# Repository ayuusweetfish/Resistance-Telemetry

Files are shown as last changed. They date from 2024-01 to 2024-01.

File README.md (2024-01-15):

# Resistance Telemetry

*🚧 Feature complete. Docs to be polished.*

A compact sensor for a variable resistance that transmits data through BLE. A client program provides an interface for plotting and inspecting values on a desktop computer.

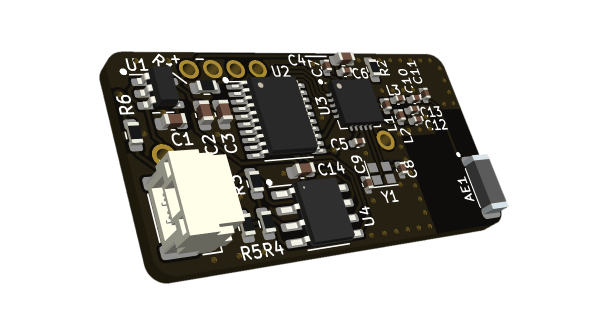
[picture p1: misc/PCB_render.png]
Rendering of the circuit board


The device is physically compact (3.3 cm × 1.7 cm, around the size of the battery cell plus the antenna). It is powered by a LIR2016 cell and requires no setup on the computer side. Resolution is 24-bit, but no extensive calibration has currently been carried out. Designed for laboratory use, e.g. for e-skin gloves user studies.

## Directory structure

- **hardware/**: Circuit board design files.
- **firmware/**: Firmware (PlatformIO / C).
- **client/**: The client in C++. A Windows build is automated through [GitHub Actions](https://github.com/ayuusweetfish/Resistance-Telemetry/actions).
- **misc/**: Miscellaneous files and backups.
  - **STM32F1_test1/**: Test BLE transmission on a [blue pill](https://stm32-base.org/boards/STM32F103C8T6-Blue-Pill.html) board.
  - **compress_24b.c**: Data compression through least-squares quadratic fitting. Not employed in the final version due to nonnecessity for further enhancement.

## Permit

All content in this repository is released under [CC BY-NC-SA 4.0](https://creativecommons.org/licenses/by-nc-sa/4.0/). Additionally, software source code is dual-licensed by [Hippocratic License 2.1](https://spdx.org/licenses/Hippocratic-2.1.html).

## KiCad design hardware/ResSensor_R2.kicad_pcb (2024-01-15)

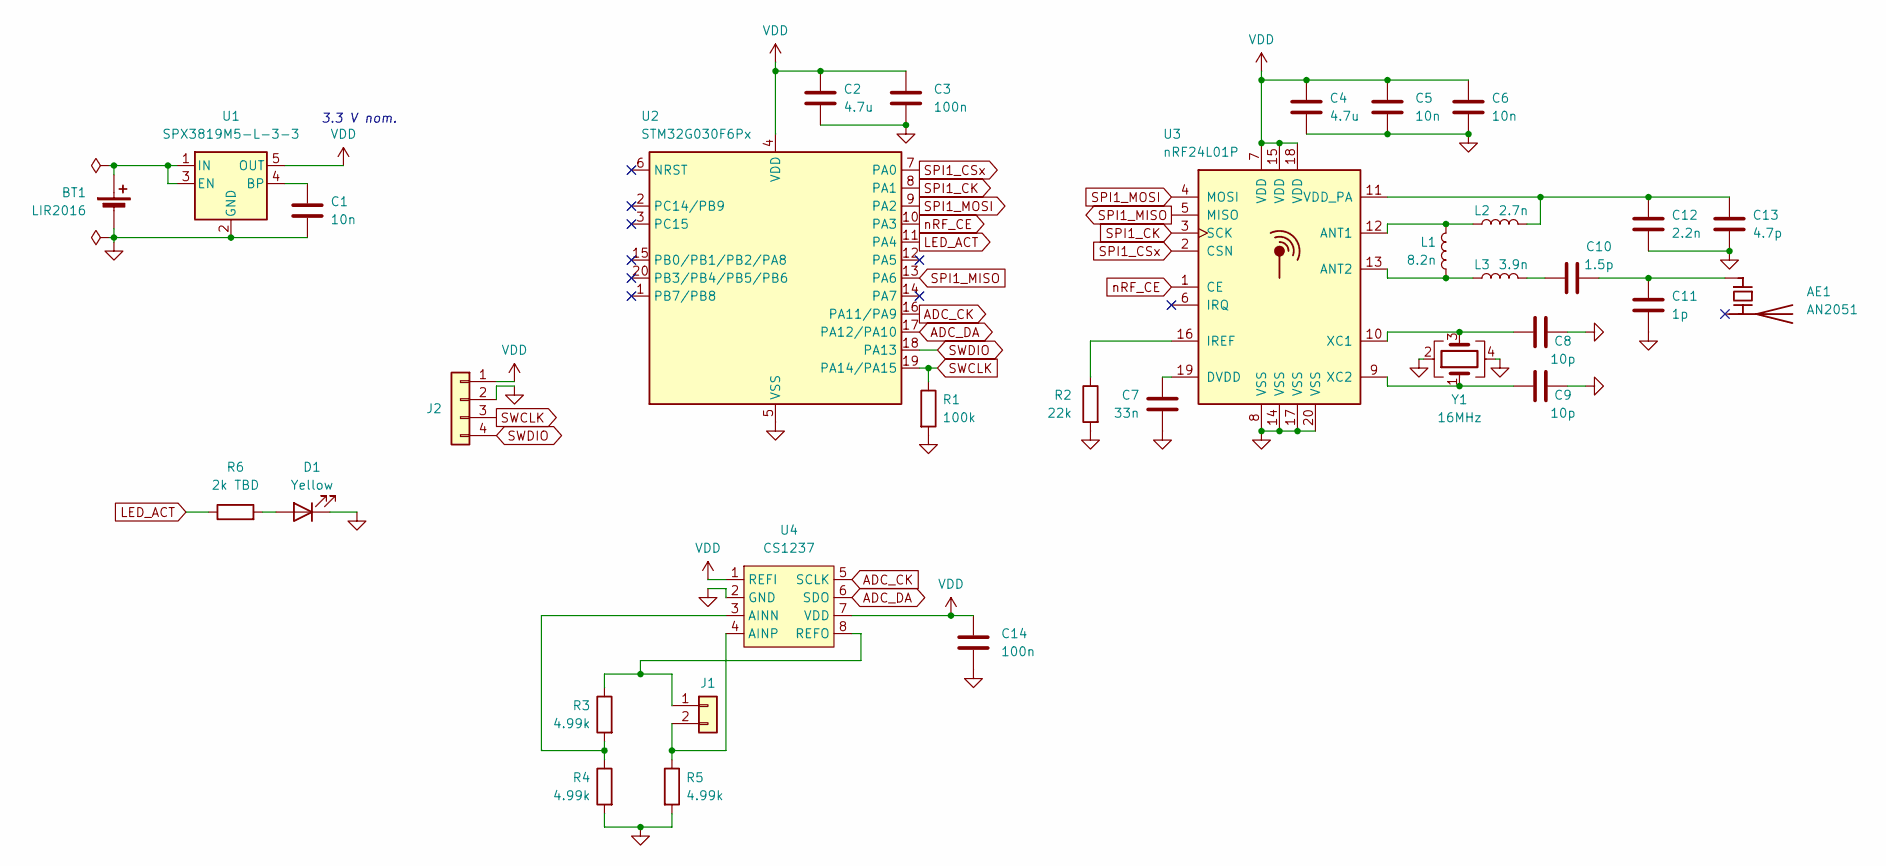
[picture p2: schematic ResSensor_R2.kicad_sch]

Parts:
AE1: AN2051; ANTC5020X127N
BT1: LIR2016; BatteryHolder_2032_THT_P20
C1: 10n; C_0603_1608Metric
C2, C4: 4.7u; C_0603_1608Metric
C3, C14: 100n; C_0603_1608Metric
C5, C6: 10n; C_0402_1005Metric
C7: 33n; C_0402_1005Metric
C8, C9: 10p; C_0402_1005Metric
C10: 1.5p; C_0402_1005Metric
C11: 1p; C_0402_1005Metric
C12: 2.2n; C_0402_1005Metric
C13: 4.7p; C_0402_1005Metric
D1: Yellow; LED_0603_1608Metric
J1: Conn_01x02; JST_GH_SM02B-GHS-TB_1x02-1MP_P1.25mm_Horizontal
J2: Conn_01x04; TestPoints_1x04_P2.0
L1: 8.2n; C_0402_1005Metric
L2: 2.7n; C_0402_1005Metric
L3: 3.9n; C_0402_1005Metric
R1: 100k; R_0603_1608Metric
R2: 22k; R_0603_1608Metric
R3, R4, R5: 4.99k; R_0603_1608Metric
R6: 2k TBD; R_0603_1608Metric
U1: SPX3819M5-L-3-3; SOT-23-5
U2: STM32G030F6Px; TSSOP-20_4.4x6.5mm_P0.65mm
U3: nRF24L01P; QFN-20-P0.5
U4: CS1237; SOP-8_3.76x4.96mm_P1.27mm
Y1: 16MHz; Crystal_SMD_2016-4Pin_2.0x1.6mm

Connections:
ADC_CK: U2.16 (PA11/PA9), U4.5 (SCLK)
ADC_DA: U2.17 (PA12/PA10), U4.6 (SDO)
GND: BT1.2 (-), C1.2, C2.2, C3.2, C4.2, C5.2, C6.2, C7.2, C8.2, C9.2, C11.2, C12.2, C13.2, C14.2, D1.1 (K), J2.2, R1.2, R2.2, R4.2, R5.2, U1.2 (GND), U2.5 (VSS), U3.8 (VSS), U3.14 (VSS), U3.17 (VSS), U3.20 (VSS), U4.2 (GND), Y1.2, Y1.4
LED_ACT: R6.1, U2.11 (PA4)
unnamed: AE1.1 (FEED), C10.2, C11.1
unnamed: BT1.1 (+), U1.1 (IN), U1.3 (EN)
unnamed: C10.1, L3.2
unnamed: D1.2 (A), R6.2
unnamed: J1.1, R3.1, U4.8 (REFO)
unnamed: J1.2, R5.1, U4.4 (AINP)
unnamed: C1.1, U1.4 (BP)
unnamed: L1.1, L2.1, U3.12 (ANT1)
unnamed: L1.2, L3.1, U3.13 (ANT2)
unnamed: C7.1, U3.19 (DVDD)
unnamed: R2.1, U3.16 (IREF)
unnamed: C12.1, C13.1, L2.2, U3.11 (VDD_PA)
unnamed: C8.1, U3.10 (XC1), Y1.3
unnamed: C9.1, U3.9 (XC2), Y1.1
unnamed: R3.2, R4.1, U4.3 (AINN)
SPI1_CK: U2.8 (PA1), U3.3 (SCK)
SPI1_CSx: U2.7 (PA0), U3.2 (CSN)
SPI1_MISO: U2.13 (PA6), U3.5 (MISO)
SPI1_MOSI: U2.9 (PA2), U3.4 (MOSI)
SWCLK: J2.3, R1.1, U2.19 (PA14/PA15)
SWDIO: J2.4, U2.18 (PA13)
VDD: C2.1, C3.1, C4.1, C5.1, C6.1, C14.1, J2.1, U1.5 (OUT), U2.4 (VDD), U3.7 (VDD), U3.15 (VDD), U3.18 (VDD), U4.1 (REFI), U4.7 (VDD)
nRF_CE: U2.10 (PA3), U3.1 (CE)

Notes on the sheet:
3.3 V nom.

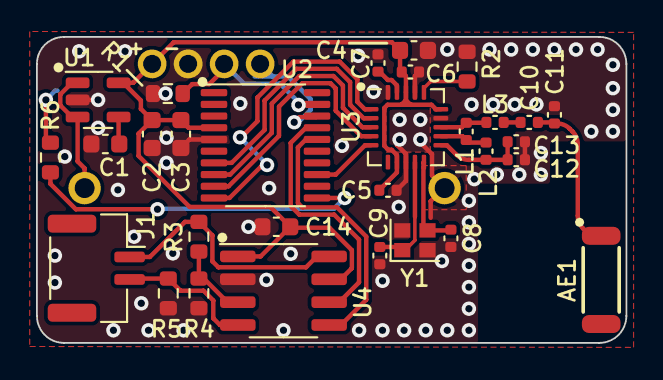
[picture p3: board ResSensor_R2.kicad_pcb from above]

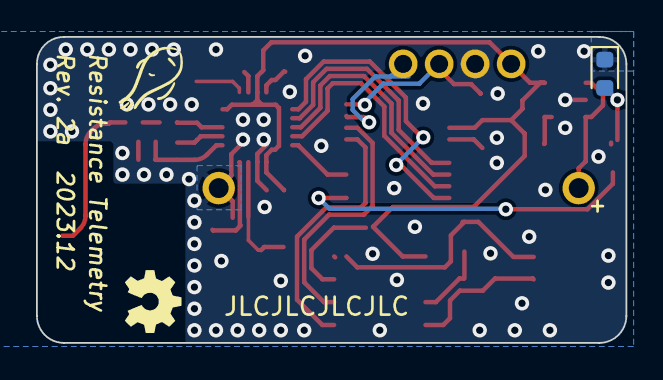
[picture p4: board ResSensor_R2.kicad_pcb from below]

Board: 2 copper layers, 32.8 x 17.0 mm, 33 parts (2 on the bottom side), 27 nets.

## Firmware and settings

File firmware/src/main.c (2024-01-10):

#include <stm32g0xx_hal.h>
#include <stdarg.h>
#include <stdbool.h>
#include <stdint.h>
#include <stdio.h>

#define LED_PORT    GPIOA
#define LED_PIN_ACT GPIO_PIN_4

#define RELEASE
#ifndef RELEASE
static uint8_t swv_buf[256];
static size_t swv_buf_ptr = 0;
__attribute__ ((noinline, used))
void swv_trap_line()
{
  *(volatile char *)swv_buf;
}
static inline void swv_putchar(uint8_t c)
{
  // ITM_SendChar(c);
  if (c == '\n') {
    swv_buf[swv_buf_ptr >= sizeof swv_buf ?
      (sizeof swv_buf - 1) : swv_buf_ptr] = '\0';
    swv_trap_line();
    swv_buf_ptr = 0;
  } else if (++swv_buf_ptr <= sizeof swv_buf) {
    swv_buf[swv_buf_ptr - 1] = c;
  }
}
static void swv_printf(const char *restrict fmt, ...)
{
  char s[256];
  va_list args;
  va_start(args, fmt);
  int r = vsnprintf(s, sizeof s, fmt, args);
  for (int i = 0; i < r && i < sizeof s - 1; i++) swv_putchar(s[i]);
  if (r >= sizeof s) {
    for (int i = 0; i < 3; i++) swv_putchar('.');
    swv_putchar('\n');
  }
}
#else
#define swv_printf(...)
#endif

#define PIN_ADC_CK  GPIO_PIN_11
#define PIN_ADC_DA  GPIO_PIN_12
void adc_configure();

SPI_HandleTypeDef spi1 = { 0 };
#define PIN_nRF_CS  GPIO_PIN_0
#define PIN_nRF_CE  GPIO_PIN_3

TIM_HandleTypeDef tim14;

// Disabled; see notes in main()
// ADC_HandleTypeDef adc1 = { 0 };

static inline void sleep_delay(uint32_t ticks) {
  uint32_t start_tick = HAL_GetTick();
  while (HAL_GetTick() - start_tick < ticks + 1)
    HAL_PWR_EnterSLEEPMode(PWR_MAINREGULATOR_ON, PWR_SLEEPENTRY_WFI);
}
#define HAL_Delay sleep_delay

static inline void nRF_send_len(const uint8_t *cmd, uint32_t size)
{
  HAL_GPIO_WritePin(GPIOA, PIN_nRF_CS, GPIO_PIN_RESET);
  HAL_SPI_Transmit(&spi1, (uint8_t *)cmd, size, 1000);
  HAL_GPIO_WritePin(GPIOA, PIN_nRF_CS, GPIO_PIN_SET);
}
#define nRF_send(...) do { \
  uint8_t buf[] = {__VA_ARGS__}; \
  nRF_send_len(buf, sizeof buf); \
} while (0)

static inline uint8_t bit_rev(uint8_t x)
{
  x = (x & 0b00001111) << 4 | (x & 0b11110000) >> 4;
  x = (x & 0b00110011) << 2 | (x & 0b11001100) >> 2;
  x = (x & 0b01010101) << 1 | (x & 0b10101010) >> 1;
  return x;
}

static inline void ble_encode_packet(uint8_t *packet, uint8_t len, uint8_t ch)
{
  // CRC
  uint8_t crc[3] = {0x55, 0x55, 0x55};
  for (uint8_t i = 0; i < len; i++) {
    uint8_t d = packet[i];
    for (uint8_t v = 0; v < 8; v++, d >>= 1) {
      uint8_t t = 0;
      if (crc[0] & 0x80) { t = 1;       } crc[0] <<= 1;
      if (crc[1] & 0x80) { crc[0] |= 1; } crc[1] <<= 1;
      if (crc[2] & 0x80) { crc[1] |= 1; } crc[2] <<= 1;
      if (t != (d & 1)) {
        crc[2] ^= 0x5B;
        crc[1] ^= 0x06;
      }
    }
  }
  packet[len + 0] = bit_rev(crc[0]);
  packet[len + 1] = bit_rev(crc[1]);
  packet[len + 2] = bit_rev(crc[2]);

  // Whiten
  uint8_t whiten_coeff = bit_rev(ch) | 2;
  for (uint8_t i = 0; i < len + 3; i++) {
    for (uint8_t m = 1; m != 0; m <<= 1) {
      if (whiten_coeff & 0x80) {
        whiten_coeff ^= 0x11;
        packet[i] ^= m;
      }
      whiten_coeff <<= 1;
    }
  }

  // Reverse all bits
  for (uint8_t i = 0; i < len + 3; i++)
    packet[i] = bit_rev(packet[i]);
}

static inline void write_bits(uint8_t *buffer, size_t start, size_t length, uint32_t value)
{
  for (int i = 0; i < length; i++) {
    int index = (start + i) / 8;
    int bitpos = (start + i) % 8;
    if (value & (1 << i))
      buffer[index] |= (1 << bitpos);
    else
      buffer[index] &= ~(1 << bitpos);
  }
}

static volatile uint32_t adc_value = 0;
static volatile uint8_t adc_updated = 0;

int main()
{
  HAL_Init();

  // ======== GPIO ========
  __HAL_RCC_GPIOA_CLK_ENABLE();
  GPIO_InitTypeDef gpio_init;

  gpio_init.Pin = LED_PIN_ACT;
  gpio_init.Mode = GPIO_MODE_OUTPUT_PP;
  gpio_init.Pull = GPIO_PULLUP;
  gpio_init.Speed = GPIO_SPEED_FREQ_HIGH;
  HAL_GPIO_Init(LED_PORT, &gpio_init);
  HAL_GPIO_WritePin(LED_PORT, LED_PIN_ACT, GPIO_PIN_RESET);

  // SWD (PA13, PA14)
  gpio_init.Pin = GPIO_PIN_13 | GPIO_PIN_14;
  gpio_init.Mode = GPIO_MODE_AF_PP; // Pass over control to AF peripheral
  gpio_init.Alternate = GPIO_AF0_SWJ;
  gpio_init.Pull = GPIO_PULLUP;
  gpio_init.Speed = GPIO_SPEED_FREQ_HIGH;
  HAL_GPIO_Init(GPIOA, &gpio_init);

  // Clocks
  RCC_OscInitTypeDef osc_init = { 0 };
  osc_init.OscillatorType = RCC_OSCILLATORTYPE_HSI;
  osc_init.HSIState = RCC_HSI_ON;
  osc_init.HSIDiv = RCC_HSI_DIV8;
  osc_init.PLL.PLLState = RCC_PLL_OFF;
  HAL_RCC_OscConfig(&osc_init);

  RCC_ClkInitTypeDef clk_init = { 0 };
  clk_init.ClockType =
    RCC_CLOCKTYPE_SYSCLK |
    RCC_CLOCKTYPE_HCLK |
    RCC_CLOCKTYPE_PCLK1;
  clk_init.SYSCLKSource = RCC_SYSCLKSOURCE_HSI; // SYSCLK = HCLK = 2 MHz
  clk_init.AHBCLKDivider = RCC_SYSCLK_DIV1;
  clk_init.APB1CLKDivider = RCC_HCLK_DIV1;
  HAL_RCC_ClockConfig(&clk_init, FLASH_LATENCY_2);

  HAL_NVIC_SetPriority(SysTick_IRQn, 0, 0);

  HAL_GPIO_WritePin(GPIOA, PIN_ADC_CK, GPIO_PIN_SET);

  // ======== SPIx ADC ========
  HAL_Delay(1);
  // ADC_CK
  gpio_init.Pin = PIN_ADC_CK;
  gpio_init.Mode = GPIO_MODE_OUTPUT_PP;
  gpio_init.Pull = GPIO_NOPULL;
  gpio_init.Speed = GPIO_SPEED_FREQ_HIGH;
  HAL_GPIO_Init(GPIOA, &gpio_init);
  // ADC_DA
  gpio_init.Pin = PIN_ADC_DA;
  gpio_init.Mode = GPIO_MODE_INPUT;
  gpio_init.Pull = GPIO_NOPULL;
  gpio_init.Speed = GPIO_SPEED_FREQ_HIGH;
  HAL_GPIO_Init(GPIOA, &gpio_init);

  HAL_GPIO_WritePin(GPIOA, PIN_ADC_CK, GPIO_PIN_RESET);
  HAL_Delay(1);
  // Wait for DRDY (not necessary — see below)
  // while (HAL_GPIO_ReadPin(GPIOA, PIN_ADC_DA) == GPIO_PIN_SET) { }
  // XXX: Are these unarticulated design aspects inside CS1237?
  //   Configuration cannot be processed when data conversion is in progress?
  //   DRDY is still present when data is invalid during the first 3/4 samples?
  // Anyway, blink the LED while we wait
  HAL_GPIO_WritePin(LED_PORT, LED_PIN_ACT, GPIO_PIN_SET);
  HAL_Delay(160);
  HAL_GPIO_WritePin(LED_PORT, LED_PIN_ACT, GPIO_PIN_RESET);
  HAL_Delay(160);
  adc_configure();  // Read data (discarded) and configure
  HAL_GPIO_WritePin(LED_PORT, LED_PIN_ACT, GPIO_PIN_SET);
  HAL_Delay(320);   // Skip 3 samples, otherwise the first few read-outs are zero
  HAL_GPIO_WritePin(LED_PORT, LED_PIN_ACT, GPIO_PIN_RESET);

  // PA12 - EXTI line 12
  HAL_NVIC_SetPriority(EXTI4_15_IRQn, 2, 0);
  HAL_NVIC_EnableIRQ(EXTI4_15_IRQn);

  // Pull down clock / chip select signal and wait for DRDY
  HAL_GPIO_WritePin(GPIOA, PIN_ADC_CK, GPIO_PIN_RESET);

  // ======== SPI ========
  // GPIO ports
  // SPI1_SCK (PA1), SPI1_MOSI (PA2), SPI1_MISO (PA6)
  gpio_init.Pin = GPIO_PIN_1 | GPIO_PIN_2 | GPIO_PIN_6;
  gpio_init.Mode = GPIO_MODE_AF_PP;
  gpio_init.Alternate = GPIO_AF0_SPI1;
  gpio_init.Pull = GPIO_NOPULL;
  gpio_init.Speed = GPIO_SPEED_FREQ_HIGH;
  HAL_GPIO_Init(GPIOA, &gpio_init);
  // nRF24L01+ CSN (PA0)
  gpio_init.Mode = GPIO_MODE_OUTPUT_PP;
  gpio_init.Pin = PIN_nRF_CS | PIN_nRF_CE;
  HAL_GPIO_Init(GPIOA, &gpio_init);
  HAL_GPIO_WritePin(GPIOA, PIN_nRF_CS, GPIO_PIN_SET);
  HAL_GPIO_WritePin(GPIOA, PIN_nRF_CE, GPIO_PIN_RESET);

  __HAL_RCC_SPI1_CLK_ENABLE();
  spi1.Instance = SPI1;
  spi1.Init.Mode = SPI_MODE_MASTER;
  spi1.Init.Direction = SPI_DIRECTION_2LINES;
  spi1.Init.CLKPolarity = SPI_POLARITY_LOW; // CPOL = 0
  spi1.Init.CLKPhase = SPI_PHASE_1EDGE;     // CPHA = 0
  spi1.Init.NSS = SPI_NSS_SOFT;
  spi1.Init.FirstBit = SPI_FIRSTBIT_MSB;
  spi1.Init.TIMode = SPI_TIMODE_DISABLE;
  spi1.Init.CRCCalculation = SPI_CRCCALCULATION_DISABLE;
  spi1.Init.DataSize = SPI_DATASIZE_8BIT;
  spi1.Init.BaudRatePrescaler = SPI_BAUDRATEPRESCALER_2;
  HAL_SPI_Init(&spi1);
  __HAL_SPI_ENABLE(&spi1);

  // Set up nRF24L01+
  nRF_send(0x20, 0x72); // CONFIG: Disable IRQ and CRC, power up
  nRF_send(0x21, 0x00); // EN_AA: Disable auto ack.
  nRF_send(0x22, 0x00); // EN_RXADDR: Disable RX completely
  nRF_send(0x23, 0x02); // SETUP_AW: 4-byte address
  nRF_send(0x24, 0x00); // SETUP_RETR: Disable auto restransmission
  nRF_send(0x26, 0x06); // RF_SETUP: 1 Mbps, 0 dBm
  nRF_send(0x27, 0x70); // STATUS: Clear status flags
  // nRF_send(0x31, 32);   // RX_PW_P0: Pipe 0 payload length 32 bytes
  nRF_send(0x22, 0x01); // EN_RXADDR: Enable RX on pipe 0
  // nRF_send(0x2A, bit_rev(0x8E), bit_rev(0x89), bit_rev(0xBE), bit_rev(0xD6));
    // RX_ADDR_P0: Set pipe 0 receive address
  nRF_send(0x30, bit_rev(0x8E), bit_rev(0x89), bit_rev(0xBE), bit_rev(0xD6));
    // TX_ADDR: Set transmit address

  // Read register 0x06 (RF_SETUP)
  HAL_GPIO_WritePin(GPIOA, PIN_nRF_CS, GPIO_PIN_RESET);
  uint8_t spi_tx[2] = {0x06, 0x00};
  uint8_t spi_rx[2];
  HAL_SPI_TransmitReceive(&spi1, spi_tx, spi_rx, 2, 1000);
  HAL_GPIO_WritePin(GPIOA, PIN_nRF_CS, GPIO_PIN_SET);
  swv_printf("received data = %02x %02x\n", spi_rx[0], spi_rx[1]);
  if (spi_rx[0] != 0x0E || spi_rx[1] != 0x06) {
    // Error? Try a reset
    for (int i = 0; i < 11; i++) {
      HAL_GPIO_WritePin(LED_PORT, LED_PIN_ACT, i % 2);
      HAL_Delay(60);
    }
    HAL_Delay(500);
    NVIC_SystemReset();
  }

  // ======== Timer ========
  // APB1 = 2 MHz
  // period = 1 kHz = 2000 cycles
  // Act LED, TIM14
  gpio_init.Pin = LED_PIN_ACT;
  gpio_init.Mode = GPIO_MODE_AF_PP;
  gpio_init.Alternate = GPIO_AF4_TIM14;
  gpio_init.Pull = GPIO_NOPULL;
  gpio_init.Speed = GPIO_SPEED_FREQ_HIGH;
  HAL_GPIO_Init(LED_PORT, &gpio_init);
  __HAL_RCC_TIM14_CLK_ENABLE();
  tim14 = (TIM_HandleTypeDef){
    .Instance = TIM14,
    .Init = {
      .Prescaler = 1 - 1,
      .CounterMode = TIM_COUNTERMODE_UP,
      .Period = 2000 - 1,
      .ClockDivision = TIM_CLOCKDIVISION_DIV1,
      .RepetitionCounter = 0,
    },
  };
  HAL_TIM_PWM_Init(&tim14);
  TIM_OC_InitTypeDef tim14_ch1_oc_init = {
    .OCMode = TIM_OCMODE_PWM1,
    .Pulse = 0, // to be filled
    .OCPolarity = TIM_OCPOLARITY_HIGH,
  };
  HAL_TIM_PWM_ConfigChannel(&tim14, &tim14_ch1_oc_init, TIM_CHANNEL_1);
  HAL_TIM_PWM_Start(&tim14, TIM_CHANNEL_1);
/*
from math import *
N=256
print(', '.join('%d' % round(600*((1+sin(i/N*2*pi))/2)**2) for i in range(N)))
*/
  static const uint16_t LED_STEPS[] = {
150, 157, 165, 173, 181, 189, 197, 206, 214, 223, 232, 241, 250, 259, 268, 277, 287, 296, 306, 315, 325, 334, 344, 353, 363, 372, 382, 391, 401, 410, 419, 428, 437, 446, 455, 463, 472, 480, 488, 496, 503, 511, 518, 525, 531, 538, 544, 550, 555, 560, 565, 570, 574, 578, 582, 586, 589, 591, 594, 595, 597, 598, 599, 600, 600, 600, 599, 598, 597, 595, 594, 591, 589, 586, 582, 578, 574, 570, 565, 560, 555, 550, 544, 538, 531, 525, 518, 511, 503, 496, 488, 480, 472, 463, 455, 446, 437, 428, 419, 410, 401, 391, 382, 372, 363, 353, 344, 334, 325, 315, 306, 296, 287, 277, 268, 259, 250, 241, 232, 223, 214, 206, 197, 189, 181, 173, 165, 157, 150, 143, 136, 129, 122, 116, 109, 103, 97, 91, 86, 81, 76, 71, 66, 61, 57, 53, 49, 45, 42, 39, 35, 32, 30, 27, 25, 22, 20, 18, 16, 14, 13, 11, 10, 9, 8, 7, 6, 5, 4, 4, 3, 3, 2, 2, 1, 1, 1, 1, 1, 0, 0, 0, 0, 0, 0, 0, 0, 0, 0, 0, 0, 0, 0, 0, 0, 0, 0, 0, 0, 0, 0, 0, 0, 0, 0, 0, 1, 1, 1, 1, 1, 2, 2, 3, 3, 4, 4, 5, 6, 7, 8, 9, 10, 11, 13, 14, 16, 18, 20, 22, 25, 27, 30, 32, 35, 39, 42, 45, 49, 53, 57, 61, 66, 71, 76, 81, 86, 91, 97, 103, 109, 116, 122, 129, 136, 143
  };

  // ======== On-chip ADC ========
  // Disabled; HAL_ADC_GetValue() disturbs timing of CS1237?
/*
  __HAL_RCC_ADC_CLK_ENABLE();
  adc1.Instance = ADC1;
  adc1.Init.ClockPrescaler = ADC_CLOCK_ASYNC_DIV1;
  adc1.Init.Resolution = ADC_RESOLUTION_12B;
  adc1.Init.DataAlign = ADC_DATAALIGN_RIGHT;
  adc1.Init.ScanConvMode = ADC_SCAN_DISABLE;
  adc1.Init.EOCSelection = ADC_EOC_SINGLE_CONV;
  adc1.Init.LowPowerAutoWait = DISABLE;
  adc1.Init.LowPowerAutoPowerOff = ENABLE;
  adc1.Init.ContinuousConvMode = DISABLE;
  adc1.Init.NbrOfConversion = 1;
  adc1.Init.DiscontinuousConvMode = DISABLE;
  adc1.Init.ExternalTrigConv = ADC_SOFTWARE_START;
  adc1.Init.TriggerFrequencyMode = ADC_TRIGGER_FREQ_LOW;
  HAL_ADC_Init(&adc1);

  ADC_ChannelConfTypeDef adc_ch;
  adc_ch.Channel = ADC_CHANNEL_VREFINT;
  adc_ch.Rank = ADC_REGULAR_RANK_1;
  adc_ch.SamplingTime = ADC_SAMPLETIME_79CYCLES_5; // Stablize
  HAL_ADC_ConfigChannel(&adc1, &adc_ch);

  HAL_ADCEx_Calibration_Start(&adc1);

  HAL_ADC_Start(&adc1);
  HAL_ADC_PollForConversion(&adc1, 1000);
  uint32_t adc_value = HAL_ADC_GetValue(&adc1);
  HAL_ADC_Stop(&adc1);
  uint32_t vdd_mV = 3000 * *VREFINT_CAL_ADDR / adc_value;
  swv_printf("ADC ref = %lu\n", *VREFINT_CAL_ADDR);
  swv_printf("ADC value = %lu, VDD = %lu mV\n", adc_value, vdd_mV);
  if (vdd_mV < 3100) {
    // Blinks: wait + 2 short + (1 long per 100 mV drop)
    HAL_Delay(200);
    for (int i = 0; i < 2; i++) {
      TIM14->CCR1 = 4000; HAL_Delay(60);
      TIM14->CCR1 = 0; HAL_Delay(60);
    }
    int blinks = (3100 - vdd_mV) / 100 + 1;
    for (int i = 0; i < blinks; i++) {
      TIM14->CCR1 = 4000; HAL_Delay(120);
      TIM14->CCR1 = 0; HAL_Delay(120);
    }
  }
*/

  uint8_t nrf_ch[3] = { 2, 26, 80};
  uint8_t ble_ch[3] = {37, 38, 39};
  uint8_t cur_ch = 2;

  uint8_t led_phase = 0;
  uint16_t timestamp = 0;
  uint32_t collected_data[15] = { 0 };

  uint8_t cur_offset_counter = 0;
  uint8_t startup_counter = 0;  // Counts up to 15, then stops

  while (!adc_updated) { }  // Wait for the first sample

  uint32_t last_tick = HAL_GetTick();
  while (true) {
    cur_ch = (cur_ch + 1) % 3;
    if (adc_updated) {
      timestamp += 1;   // May overflow and wrap around
      if (startup_counter < 15) startup_counter++;
      for (int i = 14; i > 0; i--) collected_data[i] = collected_data[i - 1];
      collected_data[0] = adc_value;
      adc_updated = 0;
      cur_offset_counter = 0;
    } else {
      cur_offset_counter = (cur_offset_counter + 1) % 5;
    }

    // Payload format:
    // 10 bits timestamp
    // 22*5 bits data
    uint8_t cur_offset =
      (cur_offset_counter < 3 ? 0 : (cur_offset_counter - 2) * 5);
    if (startup_counter >= 5 && startup_counter < 15) {
      // Prevent out-of-bound data
      if (cur_offset + 5 > startup_counter)
        cur_offset = startup_counter - 5;
    }
    uint8_t tx_payload[15];
    uint16_t tx_timestamp = (timestamp - cur_offset) & ((1 << 10) - 1);
    write_bits(tx_payload, 0, 10, tx_timestamp);
    for (int i = 0; i < 5; i++)
      write_bits(tx_payload, 10 + i * 22, 22,
        collected_data[cur_offset + i] >> 2);

    uint8_t nRF_cmd_buf[33];
    uint8_t *buf = nRF_cmd_buf + 1;
    uint8_t p = 0;
    // PDU - Protocol Data Unit
    // AD - Advertising Data
    // For assigned numbers, see https://www.bluetooth.com/specifications/an/
    // PDU header
    buf[p++] = 0x42;  // Type: ADV_NONCONN_IND; TxAdd is random
    buf[p++] = 0;     // Payload length, to be filled
    // PDU payload
    buf[p++] = 0x48;  // Address (byte reversed)
    buf[p++] = 0xFE;
    buf[p++] = 0x21;
    buf[p++] = 0x61;
    buf[p++] = 0x75;
    buf[p++] = 0xCB;  // Highest bit should be set
  /*
    buf[p++] = 2;     // AD length
    buf[p++] = 0x01;  // Type: Flags
    buf[p++] = 0x05;
  */
    buf[p++] = 3;     // AD length
    buf[p++] = 0x08;  // Type: Shortened Local Name
    buf[p++] = 'R';
    buf[p++] = 'T';
    buf[p++] = 16;    // AD length
    buf[p++] = 0xFF;  // Type: Manufacturer Specific Data
    for (int i = 0; i < 15; i++) buf[p++] = tx_payload[i];
    buf[1] = p - 2;   // Payload length

    // Encode packet
    ble_encode_packet(buf, p, ble_ch[cur_ch]);

    nRF_send(0x25, nrf_ch[cur_ch]); // RF_CH: Set channel
    nRF_send(0x27, 0x70); // STATUS: Clear status flags
    nRF_send(0xE1); // FLUSH_TX
    nRF_send(0xE2); // FLUSH_RX
    nRF_cmd_buf[0] = 0xA0;  // W_TX_PAYLOAD
    nRF_send_len(nRF_cmd_buf, p + 4);
    HAL_GPIO_WritePin(GPIOA, PIN_nRF_CE, GPIO_PIN_SET);
    HAL_Delay(2);
    HAL_GPIO_WritePin(GPIOA, PIN_nRF_CE, GPIO_PIN_RESET);

    TIM14->CCR1 = LED_STEPS[++led_phase];
    swv_printf("ADC value = %06x\n", collected_data[0]);

    // Accurate delay
    uint32_t cur_tick = HAL_GetTick();
    if (cur_tick - last_tick >= 18) {
      last_tick = cur_tick;
    } else {
      while (HAL_GetTick() - last_tick < 18)
        HAL_PWR_EnterSLEEPMode(PWR_MAINREGULATOR_ON, PWR_SLEEPENTRY_WFI);
      last_tick += 18;
    }
  }
}

void SysTick_Handler()
{
  HAL_IncTick();
  HAL_SYSTICK_IRQHandler();
}

static inline void adc_ser_delay()
{
  // >= 0.5 us
  // SYSCLK = 2 MHz, 0.5 us is 1 cycle
  for (volatile int i = 0; i < 2; i++) asm volatile ("nop");
}

inline void adc_configure()
{
  GPIO_InitTypeDef gpio_init;
  gpio_init.Pin = PIN_ADC_DA;
  gpio_init.Pull = GPIO_NOPULL;
  gpio_init.Speed = GPIO_SPEED_FREQ_HIGH;

  HAL_GPIO_WritePin(GPIOA, PIN_ADC_CK, GPIO_PIN_RESET);
  adc_ser_delay();
  for (int i = 0; i < 29; i++) {
    HAL_GPIO_WritePin(GPIOA, PIN_ADC_CK, GPIO_PIN_SET);
    adc_ser_delay();
    HAL_GPIO_WritePin(GPIOA, PIN_ADC_CK, GPIO_PIN_RESET);
    adc_ser_delay();
  }

  gpio_init.Mode = GPIO_MODE_OUTPUT_PP;
  HAL_GPIO_Init(GPIOA, &gpio_init);
  // SPEED_SEL = 0b00: 10 Hz
  // PGA_SEL = 00: PGA gain = 1
  // ADC value normalized to [-0.5, +0.5)
  // Calculated R = R5 (see hardware design) * (1 / (0.5 + ADC value / (2^24)) - 1)
  uint8_t writes[2] = {0x65 << 1, 0b00000000};
  for (int i = 0; i < 16; i++) {
    HAL_GPIO_WritePin(GPIOA, PIN_ADC_CK, GPIO_PIN_SET);
    HAL_GPIO_WritePin(GPIOA, PIN_ADC_DA, (writes[i / 8] >> (7 - i % 8)) & 1);
    adc_ser_delay();
    HAL_GPIO_WritePin(GPIOA, PIN_ADC_CK, GPIO_PIN_RESET);
    adc_ser_delay();
  }

  gpio_init.Mode = GPIO_MODE_IT_FALLING;
  HAL_GPIO_Init(GPIOA, &gpio_init);
  HAL_GPIO_WritePin(GPIOA, PIN_ADC_CK, GPIO_PIN_SET);
  adc_ser_delay();
  HAL_GPIO_WritePin(GPIOA, PIN_ADC_CK, GPIO_PIN_RESET);
  adc_ser_delay();
}

static inline uint32_t adc_read()
{
  uint32_t value = 0;
  for (int i = 0; i < 24; i++) {
    HAL_GPIO_WritePin(GPIOA, PIN_ADC_CK, GPIO_PIN_SET);
    adc_ser_delay();
    uint32_t bit = HAL_GPIO_ReadPin(GPIOA, PIN_ADC_DA);
    value = (value << 1) | bit;
    HAL_GPIO_WritePin(GPIOA, PIN_ADC_CK, GPIO_PIN_RESET);
    adc_ser_delay();
  }
  return value;
}

void EXTI4_15_IRQHandler()
{
  adc_value = adc_read();
  adc_updated = 1;
  __HAL_GPIO_EXTI_CLEAR_FALLING_IT(PIN_ADC_DA);
}

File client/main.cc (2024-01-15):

// c++ % -ISimpleBLE/simpleble/include -Ibuild_simpleble/export build_simpleble/lib/libsimpleble.a -Ilibmicrohttpd-0.9.77/src/include libmicrohttpd-0.9.77/src/microhttpd/.libs/libmicrohttpd.a -std=c++17 -framework CoreBluetooth -framework Foundation

#include "simpleble/SimpleBLE.h"
#include "microhttpd.h"

#include <cassert>
#include <cerrno>
#include <climits>    // INT_MAX
#include <cstdio>
#include <cstdlib>
#include <cstring>
#if defined(WIN32) || defined(_WIN32)
#include <windows.h>
#define sleep(x) Sleep(1000 * (x))
#else
#include <unistd.h>
#endif

#include <algorithm>  // std::upper_bound
#include <deque>
#include <iomanip>    // std::setprecision
#include <mutex>
#include <sstream>    // std::ostringstream
#include <utility>    // std::pair
#include <vector>

#define USE_BUILTIN_INDEX_HTML 1
#if USE_BUILTIN_INDEX_HTML
// xxd -i index.html > index.html.h
#include "index.html.h"
// unsigned char index_html[]
// unsigned int index_html_len
#else
unsigned char index_html[4000000];
unsigned int index_html_len;
#endif

std::deque<std::pair<int, double>> readings;
std::mutex readings_mutex;
int timestamp_base = 0;
bool is_paused = false;

int main() {
#if !USE_BUILTIN_INDEX_HTML
  {
    FILE *f = fopen("index.html", "rb");
    fseek(f, 0, SEEK_END);
    index_html_len = ftell(f);
    fseek(f, 0, SEEK_SET);
    fread(index_html, index_html_len, 1, f);
    fclose(f);
  }
#endif

  if (!SimpleBLE::Adapter::bluetooth_enabled()) {
    printf("Bluetooth not enabled\n");
    puts("Press Enter to exit"); getchar();
    return 1;
  }

  auto adapters = SimpleBLE::Adapter::get_adapters();
  if (adapters.empty()) {
    printf("No Bluetooth adapter found\n");
    puts("Press Enter to exit"); getchar();
    return 1;
  }
  auto adapter = adapters[0];

  // Add a value to the data. This requires `readings_mutex` to be held.
  auto add_value = [] (uint32_t timestamp, uint32_t raw_adc) -> void {
    if (is_paused) return;

    // Calculate the real timestamp
    int real_timestamp = (int)timestamp + timestamp_base;
    int max_timestamp = (readings.empty() ? 0 : readings.back().first);
    if (abs(real_timestamp - max_timestamp) > 50) {
      // Out of range. Timestamp base needs to be adjusted.
      // Check whether wrapping around (both directions, as data can be out-of-order).
      if (abs((real_timestamp - 1024) - max_timestamp) <= 50) {
        timestamp_base -= 1024;
      } else if (abs((real_timestamp + 1024) - max_timestamp) <= 50) {
        timestamp_base += 1024;
      } else {  // Otherwise, simply treat the timestamp as the start of the new base.
        timestamp_base = (max_timestamp + 1) - (int)timestamp;
      }
      real_timestamp = (int)timestamp + timestamp_base;
    }

    // Calculate resistance value
    int32_t value_signed = (int32_t)(raw_adc << 10) >> 10;
    double normalized = (double)value_signed / (1 << 22);
  /*
    int32_t range_min = -0x1fd200;  // 0x202e00
    int32_t range_max =  0x1fd000;  // 0x1fd000
    double normalized =
      (double)(value_signed - range_min) / (range_max - range_min) - 0.5;
    if (normalized < -0.5) normalized = -0.5;
    if (normalized >  0.5) normalized =  0.5;
  */
    double resistance = 4990 * (1.0 / (0.5 + normalized) - 1);
    fprintf(stderr, "t = %4u (%6d): ADC =%8d  R = %12.4lf\n",
      timestamp, real_timestamp, value_signed, resistance);
    auto insert_pos = std::lower_bound(
      readings.begin(), readings.end(),
      std::make_pair(real_timestamp, -1.0));
    if (insert_pos == readings.end() || insert_pos->first != real_timestamp)
      readings.insert(insert_pos, {real_timestamp, resistance});
  };

  auto upd_print = [add_value] (SimpleBLE::Peripheral p) {
    if (p.identifier() == "RT") {
      auto mfr_data = p.manufacturer_data();
      readings_mutex.lock();
      for (auto &[x, y] : mfr_data) {
        uint8_t payload[16];
        payload[0] = x & 0xff;
        payload[1] = (x >> 8) & 0xff;
        for (int i = 0; i < y.length(); i++) payload[i + 2] = (uint8_t)y[i];
        // for (int i = 0; i < y.length() + 2; i++) printf(" %02x", payload[i]); putchar('\n');
        auto read_bits = [] (const uint8_t *buffer, size_t start, size_t length) -> uint32_t {
          uint32_t result = 0;
          for (int i = length - 1; i >= 0; i--) {
            int index = (start + i) / 8;
            int bitpos = (start + i) % 8;
            result = (result << 1) | ((buffer[index] >> bitpos) & 1);
          }
          return result;
        };
        uint32_t start_timestamp = read_bits(payload, 0, 10);
        for (int i = 5 - 1; i >= 0; i--) {
          uint32_t timestamp = (start_timestamp - i) & ((1 << 10) - 1);
          if (timestamp >= 1000) continue;
          add_value(timestamp, read_bits(payload, 10 + i * 22, 22));
        }
      }
      readings_mutex.unlock();
    }
  };
  adapter.set_callback_on_scan_found(upd_print);
  adapter.set_callback_on_scan_updated(upd_print);

  printf("Starting scan\n");
  adapter.scan_start();

  auto request_handler = [] (
    void *cls,
    struct MHD_Connection *conn,
    const char *url,
    const char *method,
    const char *version,
    const char *upload_data,
    size_t *upload_data_size,
    void **ptr)
  -> enum MHD_Result {
    enum MHD_Result result;

    if (strcmp(method, "GET") == 0 && strcmp(url, "/") == 0) {
      struct MHD_Response *resp = MHD_create_response_from_buffer(
        index_html_len, (void *)index_html,
        MHD_RESPMEM_PERSISTENT);
      MHD_add_response_header(resp, "Content-Type", "text/html; charset=UTF-8");
      result = MHD_queue_response(conn, MHD_HTTP_OK /* 200 */, resp);
      MHD_destroy_response(resp);
      return result;
    }
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

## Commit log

2023-11-21 🎉 Initial commit, building for STM32G030
2023-11-24 Blinking pin
2023-11-24 Test DRDY signal of ADC
2023-11-25 Interrupt by DRDY
2023-11-25 Read out ADC
2023-11-25 Configure ADC PGA and sample rate
2023-11-25 SPI communication with nRF24L01+
2023-12-01 Add STM32F1 test
2023-12-01 Fix program bugs; working BTLE advertisement
    [main.c]
2023-12-04 (WIP) Port RF payload fixes back to the device
    [main.c]
2023-12-09 Sort-out; add hardware design files
    [AN2051-245.stp, ResSensor_R2.kicad_pcb, ResSensor_R2.kicad_sch]
2023-12-09 Change ADC sampling rate back to 10 Hz
2023-12-09 Calculate resistance values
2023-12-16 Revise hardware, adding indicator LED
    [ResSensor_R2.kicad_pcb, ResSensor_R2.kicad_sch]
2024-01-07 Add switch to read HTML file rather than compile-in
    For faster iteration cycles during development
2024-01-10 Fix ADC may not be correctly initialized
    [main.c]
2024-01-10 Update firmware with blinking LED
    [ResSensor_R2.kicad_pcb, ResSensor_R2.kicad_sch]
2024-01-10 Breathing LED
2024-01-10 Transmit and receive all 5 data samples
2024-01-10 Change device name and address; prepare for shipping
2024-01-10 Detect power supply level and issue warnings for low VDD
    [main.c]
2024-01-10 Enter sleep mode during delays
    Also, revert on-chip ADC due to timing issues (see notes in code)
    [main.c]
2024-01-11 Handle device resets & continuations in client
    [main.cc]
2024-01-11 Miscellaneous fixes and improvements
    [main.cc]
2024-01-11 Wait for key before quitting on errors
    [main.cc]
2024-01-15 Reorganise files and add README
    [ResSensor_R2.kicad_pcb]
